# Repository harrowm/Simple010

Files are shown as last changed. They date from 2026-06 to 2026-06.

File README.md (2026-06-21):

# Simple010

A 68010 single-board computer based on the [rosco_m68k r2](https://github.com/rosco-m68k/rosco_m68k) design. Simple010 replaces the six discrete glue-logic ICs from that design with a single **ATF1508AS PLCC84 CPLD**, reducing board complexity while adding hardware SPI acceleration for SD card access.

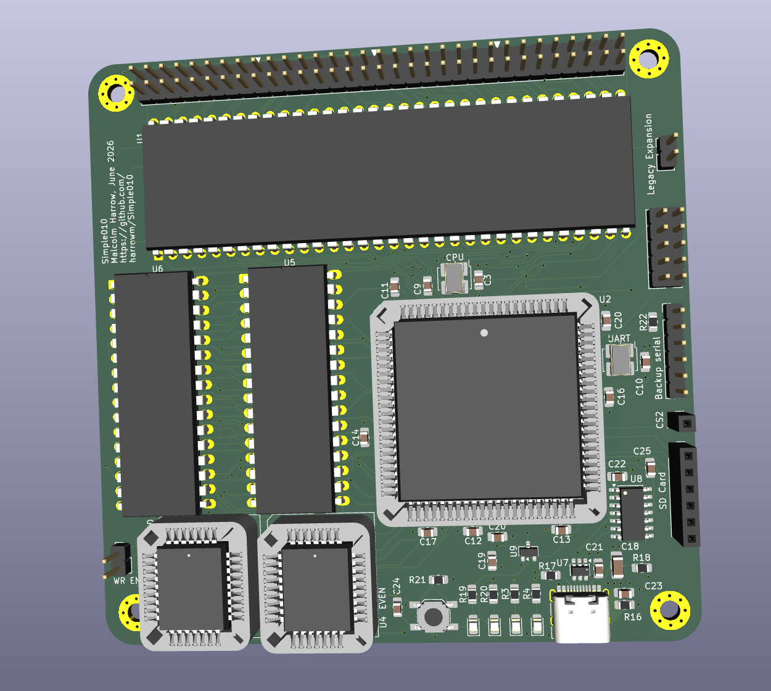
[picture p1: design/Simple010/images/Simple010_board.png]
Simple010 board


## Hardware overview

| Item | Detail |
|---|---|
| CPU | Motorola MC68010P at 10 MHz |
| RAM | 1 MB — two AS6C4008-55PCN SRAMs (even/odd byte lanes) |
| ROM | Two SST39SF040 4 Mb flash (even/odd byte lanes) |
| CPLD | ATF1508AS PLCC84 — replaces IC2/IC3/IC4/IC5/IC6/IC7 from rosco_m68k r2 |
| USB/serial | MCP2221A — USB-CDC serial to UART A. The original rosco_m68k board has two UARTs A and B. However, the code for two UARTs won't fit into the CPLD, so a cheaper one-channel USB-to-serial chip is used. |
| PCB | 4-layer, 100 × 100 mm, JLCPCB stackup (F.Cu / GND / PWR / B.Cu) |

### Memory map

| Range | Device |
|---|---|
| `$000000–$0FFFFF` | 1 MB SRAM |
| `$100000–$DFFFFF` | Expansion bus (DTACK from `LGEXP`) |
| `$E00000–$EFFFFF` | Flash ROM |
| `$F00000–$FFFFFF` | I/O — CPLD UART at `$F00000`, register select via A1–A4 |

### CPLD functional blocks

The CPLD (`code/cpld/cpld.v`) implements:

1. **Glue logic** — HALT/RESET open-drain drivers, CPU-space gating, boot flag
2. **Address decoder** — RAM, ROM, expansion, and I/O selects; DTACK; WR
3. **Watchdog** — 16-cycle timeout, asserts BERR open-drain
4. **UART A** — fixed 115200 8N1, XR68C681-compatible register map
5. **GPIO / OPR** — XR68C681 output port emulation; drives SPI CS, LEDs, MOSI, SCK
6. **SPI RX accelerator** — hardware-assisted SD card byte receive at ~1.843 MHz
7. **Interrupt priority encoder** — replaces 74LS148; encodes IRQ2/3/5/6 + UART RX into IPL2:1:0

Resource utilisation: **122/128 macro cells (95%)**.

## Repository layout

```
design/
  Simple010/            KiCad 10 schematic and PCB (1 MB SRAM)
    Simple010.kicad_sch   top-level (references four sub-sheets)
    CPU.kicad_sch         MC68010P, oscillator, expansion connector
    Memory.kicad_sch      SRAM, ROM, write-enable jumper
    CPLD.kicad_sch        ATF1508AS, JTAG header, LEDs, pull-ups
    USB.kicad_sch         MCP2221A, SD card, reset supervisor, power LEDs
    production/           Gerbers, BOM, position file
  Simple010-16/         KiCad 10 schematic and PCB (16 MB SRAM variant)
  datasheets/           component datasheets and parts index (INDEX.md)

code/cpld/       ATF1508AS Verilog RTL and testbench
  cpld.v                RTL source with //PIN: preassignment comments
  tb_cpld.v             testbench (120 assertions)
  build.sh              synthesis → fit → pin check → simulation
  cpld.jed              program this into the device
  cpld.fit / cpld.pin   fitter log and pin placement

rosco/           rosco_m68k firmware (git clone), modified for Simple010
```

## CPLD build

Requires [`atf15xx_yosys`](https://github.com/hoglet67/atf15xx_yosys.git) cloned into `~/atf15xx_yosys`, and `iverilog`/`vvp` on PATH.

```sh
cd code/cpld && ./build.sh
```

Expected output: `122/128 MCs used` and `120/120 tests passed`.

To run the testbench without re-synthesising:

```sh
cd code/cpld && iverilog -DSIMULATION -o tb_cpld tb_cpld.v cpld.v && vvp tb_cpld
```

The `-DSIMULATION` flag is required — without it 2 of 120 tests fail due to a cross-clock-domain handshake that behaves differently under deterministic simulation timing.

## Firmware

The firmware is the standard rosco_m68k r2 firmware cloned into `rosco/`, with minimal changes for Simple010 hardware.

The rosco directory is a clone of [rosco-m68k/rosco_m68k](https://github.com/rosco-m68k/rosco_m68k). Simple010 changes are on the `develop` branch, pushed to a fork at [harrowm/rosco_m68k](https://github.com/harrowm/rosco_m68k). The upstream is `origin`; the fork is `fork`:

```sh
cd rosco/rosco_m68k
git add <files>
git commit -m "description"
git push fork develop
```

### CPLD compatibility

The CPLD's UART emulates the XR68C681 (MC68681) at the register level. The existing rosco firmware DUART detection and initialisation code works without modification: the CPLD returns `0x0F` from the IVR register at reset, exactly as the real XR68C681 does.

### Simple010-specific changes

#### Startup detection — `stage1/main1.c`

At startup, after printing the standard CPU and memory information, the firmware reads the CPLD detection register and prints additional messages:

```
MC68010 CPU @ 10.0MHz with 1048576 bytes RAM
Simple010 CPLD v1 detected
  SPI RX accelerator present
```

**Detection mechanism:** reading byte address `0xF00005` (`DUART_R_MISR` in `machine.h`) returns a fixed capability byte from the CPLD:

| Bit | Mask | Meaning |
|-----|---|---|
| 7 | `0x80` | CPLD present (always 1) |
| 6 | `0x40` | SPI RX accelerator available |
| 1–0 | `0x03` | Bitstream version (currently 1) |

The combined value is `0xC1`. On the original XR68C681, this register is MISR (masked interrupt status), which reads ~`0x00` at boot — so the detection is safe on original rosco hardware and the CPLD messages simply do not appear.

> **Address note:** the CPLD's `uart_sel` is gated on `~LDS` (lower data strobe), so the access must target the **odd** byte address `0xF00005`. Reading even address `0xF00004` (upper data strobe / UDS) will not reach the CPLD.

#### SPI RX accelerator — `stage1/blockdev/bbspi.c`

The CPLD includes a hardware SPI byte-receive engine clocked at ~1.843 MHz (UART_CLK ÷ 2), reducing per-byte bus traffic from ~24 cycles to 2 cycles compared to bit-banging.

`BBSPI_initialize()` detects the accelerator by reading `0xF00005` and caches the result in a `static bool cpld_spi_accel`. `BBSPI_recv_byte()` and `BBSPI_recv_buffer()` then dispatch on this flag:

**Accelerated receive sequence (per byte):**

| Step | Action | Address |
|---|---|---|
| 1 | Write any value to SPIRX register — triggers one 8-bit receive | `0xF00009` (write) |
| 2 | Poll SRA bit 2 (`spi_busy`) until clear | `0xF00003` (read) |
| 3 | Read received byte from SPIRX register | `0xF00009` (read) |

Send operations (`BBSPI_send_byte`, `BBSPI_send_buffer`) are unchanged — they continue to bit-bang through the CPLD GPIO, which is correct since the SD card protocol is heavily read-biased and transmit calls are infrequent. On original rosco hardware, `cpld_spi_accel` is `false` and both receive functions fall back to the existing bit-bang asm routines in `dua_spi_asm.asm`.

## Parts and ordering

See [`design/datasheets/INDEX.md`](design/datasheets/INDEX.md) for a full BOM with LCSC and Mouser part numbers.

Key sourcing notes:
- **ATF1508AS-15JU84** — not on LCSC; order from Microchip direct, Mouser (556-AF1508AS15JU84), or DigiKey
- **MC68010P** — EOL; source from eBay or second-hand market
- **SST39SF040 PLCC-32** — not stocked on LCSC; use Mouser (579-SST39SF040-70-4I-NHE)

## Acknowledgements

Simple010 is based on the [rosco_m68k](https://github.com/rosco-m68k/rosco_m68k) project by Ross Bamford and contributors. The schematic topology, memory map, and firmware are derived from the rosco_m68k r2 mainboard design.

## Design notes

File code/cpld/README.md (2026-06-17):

# rosco_m68k r2 CPLD — ATF1508AS PLCC84

Replaces IC2 (address decoder), IC3 (DUART select), IC5 (glue logic),
IC6 (watchdog), IC4 (XR68C681 UART A, fixed 115200 8N1), and IC7 (74LS148
interrupt priority encoder) with a single ATF1508AS CPLD.

## Build

Requires [atf15xx_yosys](https://github.com/hoglet67/atf15xx_yosys.git) cloned
into `~/atf15xx_yosys`, and `iverilog`/`vvp` on PATH.

```
./build.sh
```

Runs synthesis, fits the design, verifies all 56 pin preassignments are
respected, then runs the testbench. Expected output:

```
Synthesising... done.
Fitting... done.  Fitter completed — 122/128 MCs used.
Checking pin assignments... all 56 assignments respected.
Running testbench... 120/120 tests passed.
```

On failure the script exits non-zero and prints the specific error (mismatched
pins or failing test assertions).

## Testing only

To run the testbench without re-synthesising:

```
iverilog -DSIMULATION -o tb_cpld tb_cpld.v cpld.v && vvp tb_cpld
```

The `-DSIMULATION` flag is required — without it only 118/120 tests pass.
The two affected tests exercise the RBA-read/cpu_rd_rba handshake: in synthesis
this is a 1-cycle SYS_CLK pulse (~124 ns) that can be missed by UART_CLK
(~270 ns period); the simulation path holds the signal until UART_CLK acks.

## Files

| File | Description |
|---|---|
| `cpld.v` | RTL source and `//PIN:` preassignment comments |
| `tb_cpld.v` | Testbench (120 assertions) |
| `build.sh` | Synthesis + fit + pin check + simulation |
| `cpld.jed` | Fitter output — program this into the device |
| `cpld.fit` | Fitter log (resource usage, pin placement) |
| `cpld.pin` | Pin placement file (generated by fitter) |

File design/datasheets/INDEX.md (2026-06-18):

# Simple010 Component Datasheets

Datasheets for all active components on the Simple010 board.
LCSC numbers are for JLCPCB ordering. Mouser numbers are for Mouser ordering.

## ICs

| Ref | Value | LCSC | Mouser | Datasheet |
|-----|---|---|---|---|
| U1 | MC68010P — 68010 CPU | — | — | [MC68010.pdf](MC68010.pdf) |
| U2 | ATF1508AS — CPLD PLCC84 | — | — | [ATF1508AS.pdf](ATF1508AS.pdf) |
| U3, U4 | SST39SF040 — 4Mb Flash ROM PLCC-32 | — (PLCC-32 not stocked on LCSC) | 579-SST39SF040-70-4I-NHE | [SST39SF040.pdf](SST39SF040.pdf) |
| U5, U6 | AS6C4008-55PCN — 512K×8 SRAM | C1350141 (OOS) | 913-AS6C4008-55PCN | [AS6C4008.pdf](AS6C4008.pdf) |
| U8 | MCP2221A — USB↔UART/I²C bridge | C640876 | 579-MCP2221A-I/SL | [MCP2221A.pdf](MCP2221A.pdf) |
| U7 | USBLC6-2SC6 — USB ESD protection | C7519 | 511-USBLC6-2SC6 | [USBLC6-2SC6.pdf](USBLC6-2SC6.pdf) |
| U9 | LM809M3-4.63/NOPB — 4.63V reset supervisor SOT-23 | C2066444 | 595-LM809M3-4.63NOPB | [LM809.pdf](LM809.pdf) |

## Oscillators

| Ref | Value | LCSC | Mouser | Datasheet |
|-----|---|---|---|---|
| Y1 | SG-5032CAN 10MHz (ECS-3961-100) — CPU clock | C41361451 | ECS-3961-100-AU-TR | [ECS-3961_SG-5032CAN.pdf](ECS-3961_SG-5032CAN.pdf) |
| Y2 | SG-5032CAN 3.6864MHz (ECS-3961-036) — UART baud clock | C5382652 | ECS-3961-036-AU-TR | [ECS-3961_SG-5032CAN.pdf](ECS-3961_SG-5032CAN.pdf) |

## LEDs

| Ref | Value | LCSC | Mouser | Datasheet |
|-----|---|---|---|---|
| LED1, LED3 | LTST-C170KGKT — 0805 Green LED | C961277 | LTST-C170KGKT | [LTST-C170KGKT.pdf](LTST-C170KGKT.pdf) |
| LED2, LED4 | LTST-C170KRKT — 0805 Red LED | C961276 | LTST-C170KRKT | [LTST-C170KRKT.pdf](LTST-C170KRKT.pdf) |

## Switches & Connectors

| Ref | Value | LCSC | Mouser | Datasheet |
|-----|---|---|---|---|
| SW1 | XKB TS-1187A-B-A-B — 5.1×5.1mm SMD tact switch | C318884 | — | [TS-1187A_SW1.pdf](TS-1187A_SW1.pdf) |
| J3 | Korean Hroparts TYPE-C-31-M-12 — USB-C receptacle 16P | C165948 | — | [TYPE-C-31-M-12_USB-C.pdf](TYPE-C-31-M-12_USB-C.pdf) |

## Passives (all 0805 unless noted)

All passives are JLCPCB **Basic** parts — no extended part setup fees.
UNI-ROYAL resistors are sold as "Royalohm" on Mouser; search by manufacturer PN.

| Value | Refs | LCSC | Manufacturer PN | Mouser |
|---|---|---|---|---|
| 100nF MLCC X7R | C1–C3, C5–C17, C20–C22, C24 | C49678 | Yageo CC0805KRX7R9BB104 | 603-CC0805KRX7R9BB104 |
| 100pF MLCC C0G/NP0 | C23 | C1790 | Samsung CL21C101JBANNNC | 187-CL21C101JBANNNC |
| 470nF MLCC X7R | C25 | C13967 | Samsung CL21B474KBFNNNE | 187-CL21B474KBFNNNE |
| 10µF MLCC X5R 25V | C4, C19 | C15850 | Samsung CL21A106KAYNNNE | 187-CL21A106KAYNNNE |
| 47µF MLCC X5R 10V **1206** | C18 | C96123 | Samsung CL31A476MPHNNNE | 187-CL31A476MPHNNNE |
| 1kΩ 1% | R3, R4, R19–R21 | C17513 | UNI-ROYAL 0805W8F1001T5E | 0805W8F1001T5E |
| 1.2kΩ 1% | R5 | C17379 | UNI-ROYAL 0805W8F1201T5E | 0805W8F1201T5E |
| 4.7kΩ 1% | R6–R15, R22 | C17673 | UNI-ROYAL 0805W8F4701T5E | 0805W8F4701T5E |
| 5.1kΩ 1% | R17, R18 | C27834 | UNI-ROYAL 0805W8F5101T5E | 0805W8F5101T5E |
| 10kΩ 1% | R1, R2 | C17414 | UNI-ROYAL 0805W8F1002T5E | 0805W8F1002T5E |
| 1MΩ 1% | R16 | C17514 | UNI-ROYAL 0805W8F1004T5E | 0805W8F1004T5E |

---

## Notes

**ATF1508AS LCSC:** The ATF1508AS-15JU84 (PLCC84, 5V, 15ns) is not stocked on LCSC/JLCPCB. Order directly from Microchip or via a distributor such as Mouser (556-AF1508AS15JU84) or DigiKey.

**MC68010P LCSC:** Not available on LCSC. Source from eBay/second-hand market, or Mouser (was stocked as NXP MC68010P10, now EOL).

**Mouser numbers** correspond to the same manufacturer as the LCSC part throughout. UNI-ROYAL resistors are listed on Mouser under the Royalohm brand; search by manufacturer PN (e.g. 0805W8F4701T5E).

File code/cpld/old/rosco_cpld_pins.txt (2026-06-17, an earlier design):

CHIP "rosco_cpld" ASSIGNED TO AN PLCC84
HWRST                : 1
SYS_CLK              : 2
VCC                  : 3
D_2                  : 4
D_0                  : 5
A20                  : 6
GND                  : 7
D_4                  : 8
nEXPSEL              : 9
nIOSEL               : 10
SPI_nCS              : 11
WR                   : 12
VCC                  : 13
TDI                  : 14
D_6                  : 15
SPI_MOSI             : 16
RW                   : 17
AS                   : 18
GND                  : 19
A23                  : 20
A22                  : 21
A21                  : 22
TMS                  : 23
D_3                  : 24
D_1                  : 25
VCC                  : 26
D_7                  : 27
D_5                  : 28
nODDROMSEL           : 29
nODDRAMSEL           : 30
nEVENRAMSEL          : 31
GND                  : 32
RXA                  : 33
A19                  : 34
UDS                  : 35
SPI_MISO             : 36
LDS                  : 37
VCC                  : 38
A4                   : 39
A1                   : 40
A3                   : 41
GND                  : 42
VCC                  : 43
nIRQ6                : 44
nIRQ3                : 45
nIRQ5                : 46
GND                  : 47
LGEXP                : 48
A18                  : 49
nIRQ2                : 50
NC                   : 51
TXA                  : 52
VCC                  : 53
FC0                  : 54
FC1                  : 55
FC2                  : 56
A2                   : 57
IPL2                 : 58
GND                  : 59
NC                   : 60
IPL0                 : 61
TCK                  : 62
NC                   : 63
NC                   : 64
NC                   : 65
VCC                  : 66
NC                   : 67
NC                   : 68
nEVENROMSEL          : 69
IPL1                 : 70
TDO                  : 71
GND                  : 72
LED_RED              : 73
SPI_nCS1             : 74
LED_GREEN            : 75
BERR                 : 76
DTACK                : 77
VCC                  : 78
RESET                : 79
HALT                 : 80
SPI_SCK              : 81
GND                  : 82
UART_CLK             : 83
NC                   : 84

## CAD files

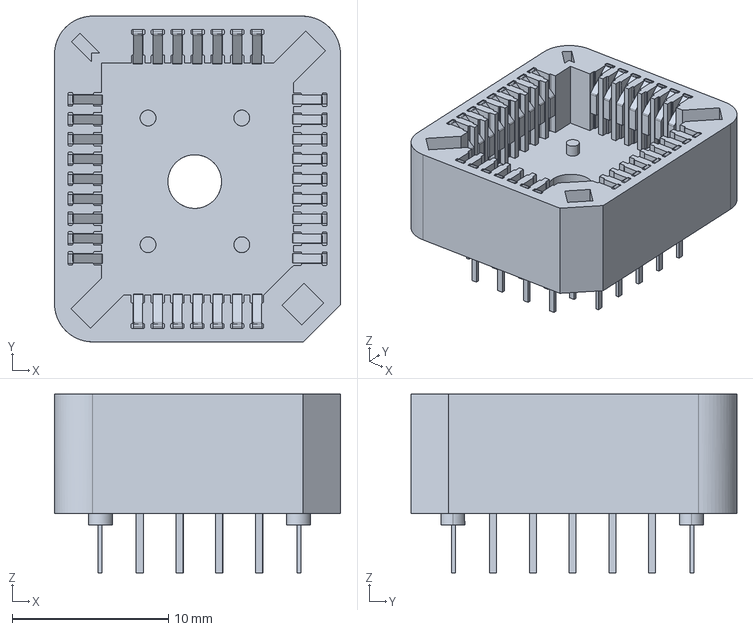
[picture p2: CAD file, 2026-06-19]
design/Simple010/3DModels/8432-11b1-01.stp
18.3 x 20.8 x 11.4 mm

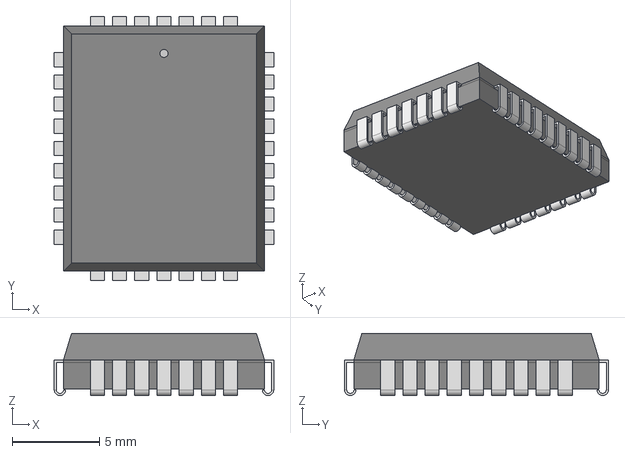
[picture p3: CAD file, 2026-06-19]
design/Simple010/3DModels/PLCC32_NH_SST_MCH.step
12.6 x 15.1 x 3.56 mm

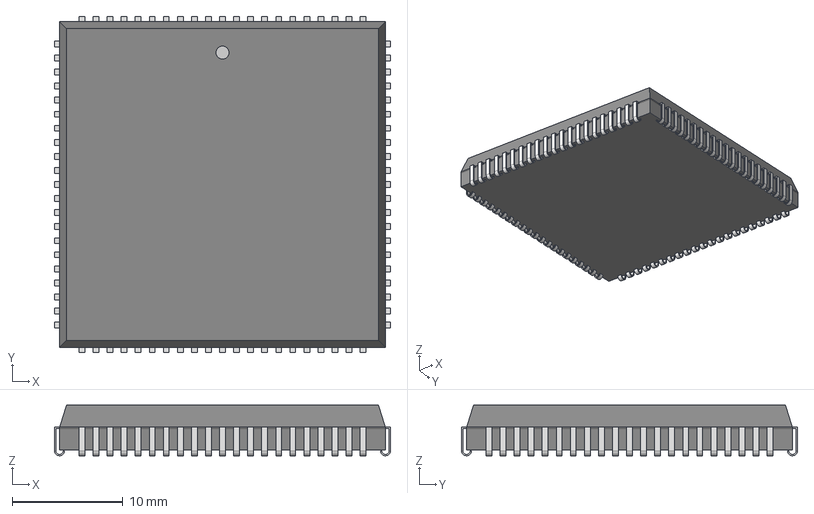
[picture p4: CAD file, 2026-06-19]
design/Simple010/3DModels/PLCC84_MCH.step
30.4 x 30.4 x 4.58 mm

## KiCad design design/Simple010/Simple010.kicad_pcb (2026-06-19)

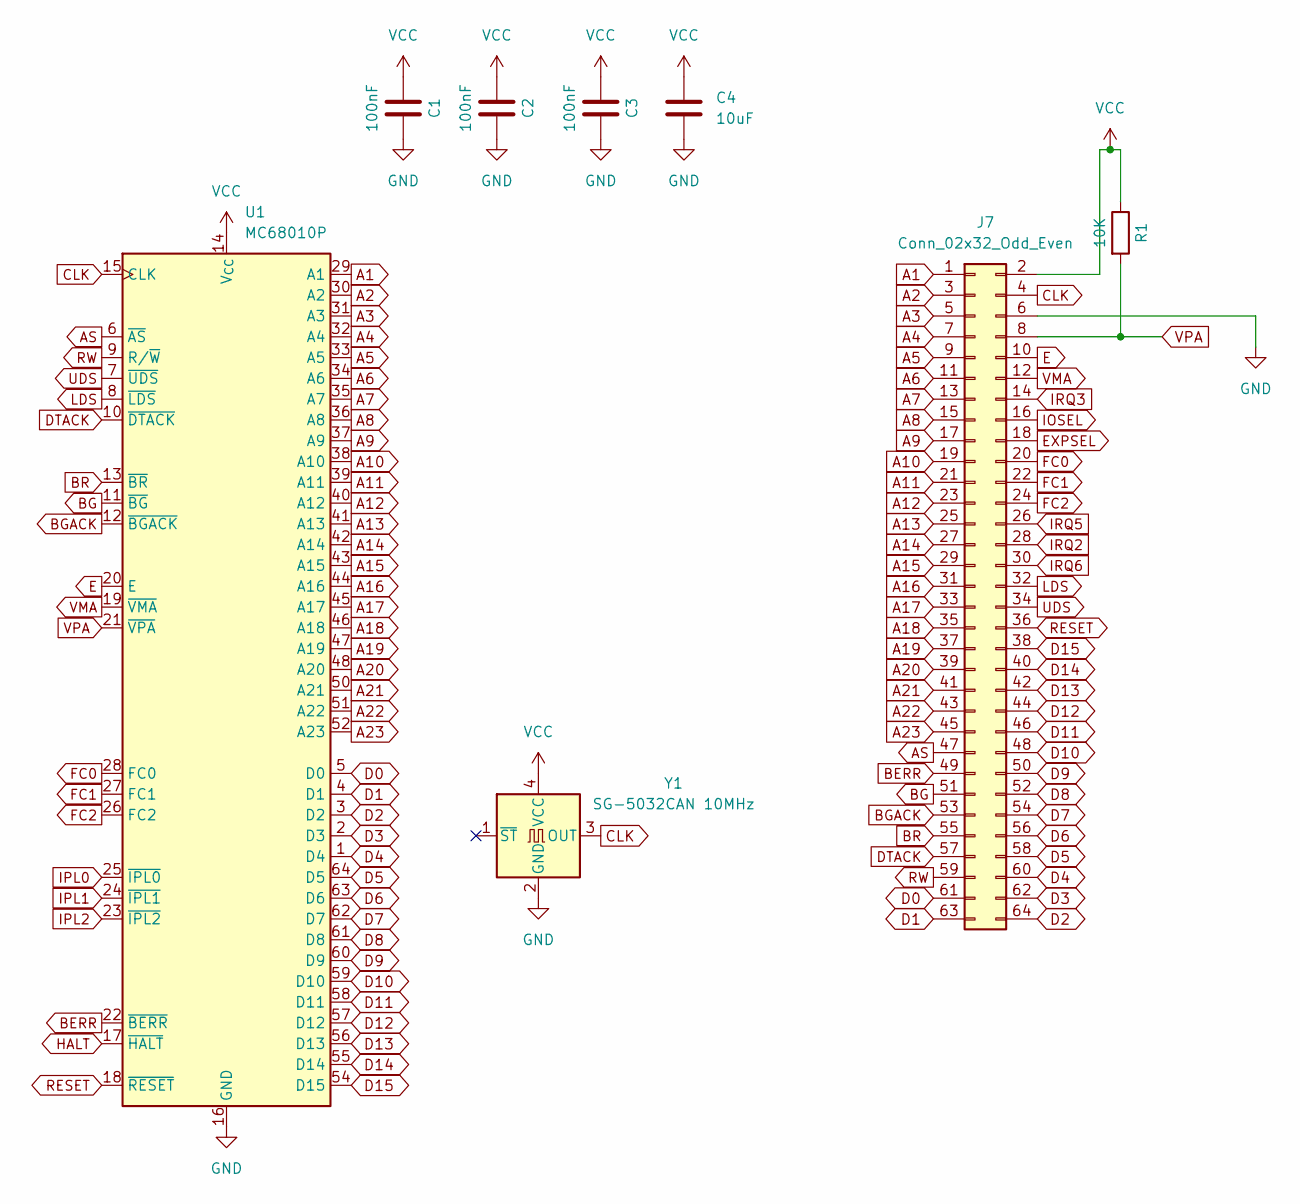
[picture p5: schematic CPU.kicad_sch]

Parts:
C1, C2, C3: 100nF; C_0805_2012Metric_Pad1.18x1.45mm_HandSolder; LCSC C49678
C4: 10uF; C_0805_2012Metric_Pad1.18x1.45mm_HandSolder; Mouser 187-CL21A106KAYNNNE
J7: Conn_02x32_Odd_Even; PinHeader_2x32_P2.54mm_Vertical
R1: 10K; R_0805_2012Metric_Pad1.20x1.40mm_HandSolder; Mouser 0805W8F1002T5E
U1: MC68010P; DIP-64_W22.86mm
Y1: SG-5032CAN 10MHz; Oscillator_SMD_SeikoEpson_SG8002LB-4Pin_5.0x3.2mm_HandSolde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; Mouser ECS-3961-100-AU-TR

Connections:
A1: J7.1, U1.29 (A1); also elsewhere on the board
A2: J7.3, U1.30 (A2); also elsewhere on the board
A3: J7.5, U1.31 (A3); also elsewhere on the board
A4: J7.7, U1.32 (A4); also elsewhere on the board
A5: J7.9, U1.33 (A5); also elsewhere on the board
A6: J7.11, U1.34 (A6); also elsewhere on the board
A7: J7.13, U1.35 (A7); also elsewhere on the board
A8: J7.15, U1.36 (A8); also elsewhere on the board
A9: J7.17, U1.37 (A9); also elsewhere on the board
A10: J7.19, U1.38 (A10); also elsewhere on the board
A11: J7.21, U1.39 (A11); also elsewhere on the board
A12: J7.23, U1.40 (A12); also elsewhere on the board
A13: J7.25, U1.41 (A13); also elsewhere on the board
A14: J7.27, U1.42 (A14); also elsewhere on the board
A15: J7.29, U1.43 (A15); also elsewhere on the board
A16: J7.31, U1.44 (A16); also elsewhere on the board
A17: J7.33, U1.45 (A17); also elsewhere on the board
A18: J7.35, U1.46 (A18); also elsewhere on the board
A19: J7.37, U1.47 (A19); also elsewhere on the board
A20: J7.39, U1.48 (A20); also elsewhere on the board
A21: J7.41, U1.50 (A21); also elsewhere on the board
A22: J7.43, U1.51 (A22); also elsewhere on the board
A23: J7.45, U1.52 (A23); also elsewhere on the board
AS: J7.47, U1.6 (~AS); also elsewhere on the board
BERR: J7.49, U1.22 (~BERR); also elsewhere on the board
BG: J7.51, U1.11 (~BG)
BGACK: J7.53, U1.12 (~BGACK); also elsewhere on the board
BR: J7.55, U1.13 (~BR); also elsewhere on the board
CLK: J7.4, U1.15 (CLK), Y1.3 (OUT); also elsewhere on the board
D0: J7.61, U1.5 (D0); also elsewhere on the board
D1: J7.63, U1.4 (D1); also elsewhere on the board
D2: J7.64, U1.3 (D2); also elsewhere on the board
D3: J7.62, U1.2 (D3); also elsewhere on the board
D4: J7.60, U1.1 (D4); also elsewhere on the board
D5: J7.58, U1.64 (D5); also elsewhere on the board
D6: J7.56, U1.63 (D6); also elsewhere on the board
D7: J7.54, U1.62 (D7); also elsewhere on the board
D8: J7.52, U1.61 (D8); also elsewhere on the board
D9: J7.50, U1.60 (D9); also elsewhere on the board
D10: J7.48, U1.59 (D10); also elsewhere on the board
D11: J7.46, U1.58 (D11); also elsewhere on the board
D12: J7.44, U1.57 (D12); also elsewhere on the board
D13: J7.42, U1.56 (D13); also elsewhere on the board
D14: J7.40, U1.55 (D14); also elsewhere on the board
D15: J7.38, U1.54 (D15); also elsewhere on the board
DTACK: J7.57, U1.10 (~DTACK); also elsewhere on the board
E: J7.10, U1.20 (E)
EXPSEL: J7.18; also elsewhere on the board
FC0: J7.20, U1.28 (FC0); also elsewhere on the board
FC1: J7.22, U1.27 (FC1); also elsewhere on the board
FC2: J7.24, U1.26 (FC2); also elsewhere on the board
GND: C1.2, C2.2, C3.2, C4.2, J7.6, U1.16 (GND), U1.53 (GND), Y1.2 (GND); also elsewhere on the board
HALT: U1.17 (~HALT); also elsewhere on the board
IOSEL: J7.16; also elsewhere on the board
IPL0: U1.25 (~IPL0); also elsewhere on the board
IPL1: U1.24 (~IPL1); also elsewhere on the board
IPL2: U1.23 (~IPL2); also elsewhere on the board
IRQ2: J7.28; also elsewhere on the board
IRQ3: J7.14; also elsewhere on the board
IRQ5: J7.26; also elsewhere on the board
IRQ6: J7.30; also elsewhere on the board
LDS: J7.32, U1.8 (~LDS); also elsewhere on the board
RESET: J7.36, U1.18 (~RESET); also elsewhere on the board
RW: J7.59, U1.9 (R/~W); also elsewhere on the board
UDS: J7.34, U1.7 (~UDS); also elsewhere on the board
VCC: C1.1, C2.1, C3.1, C4.1, J7.2, R1.1, U1.14 (V_{CC}), U1.49 (V_{CC}), Y1.4 (VCC); also elsewhere on the board
VMA: J7.12, U1.19 (~VMA)
VPA: J7.8, R1.2, U1.21 (~VPA)

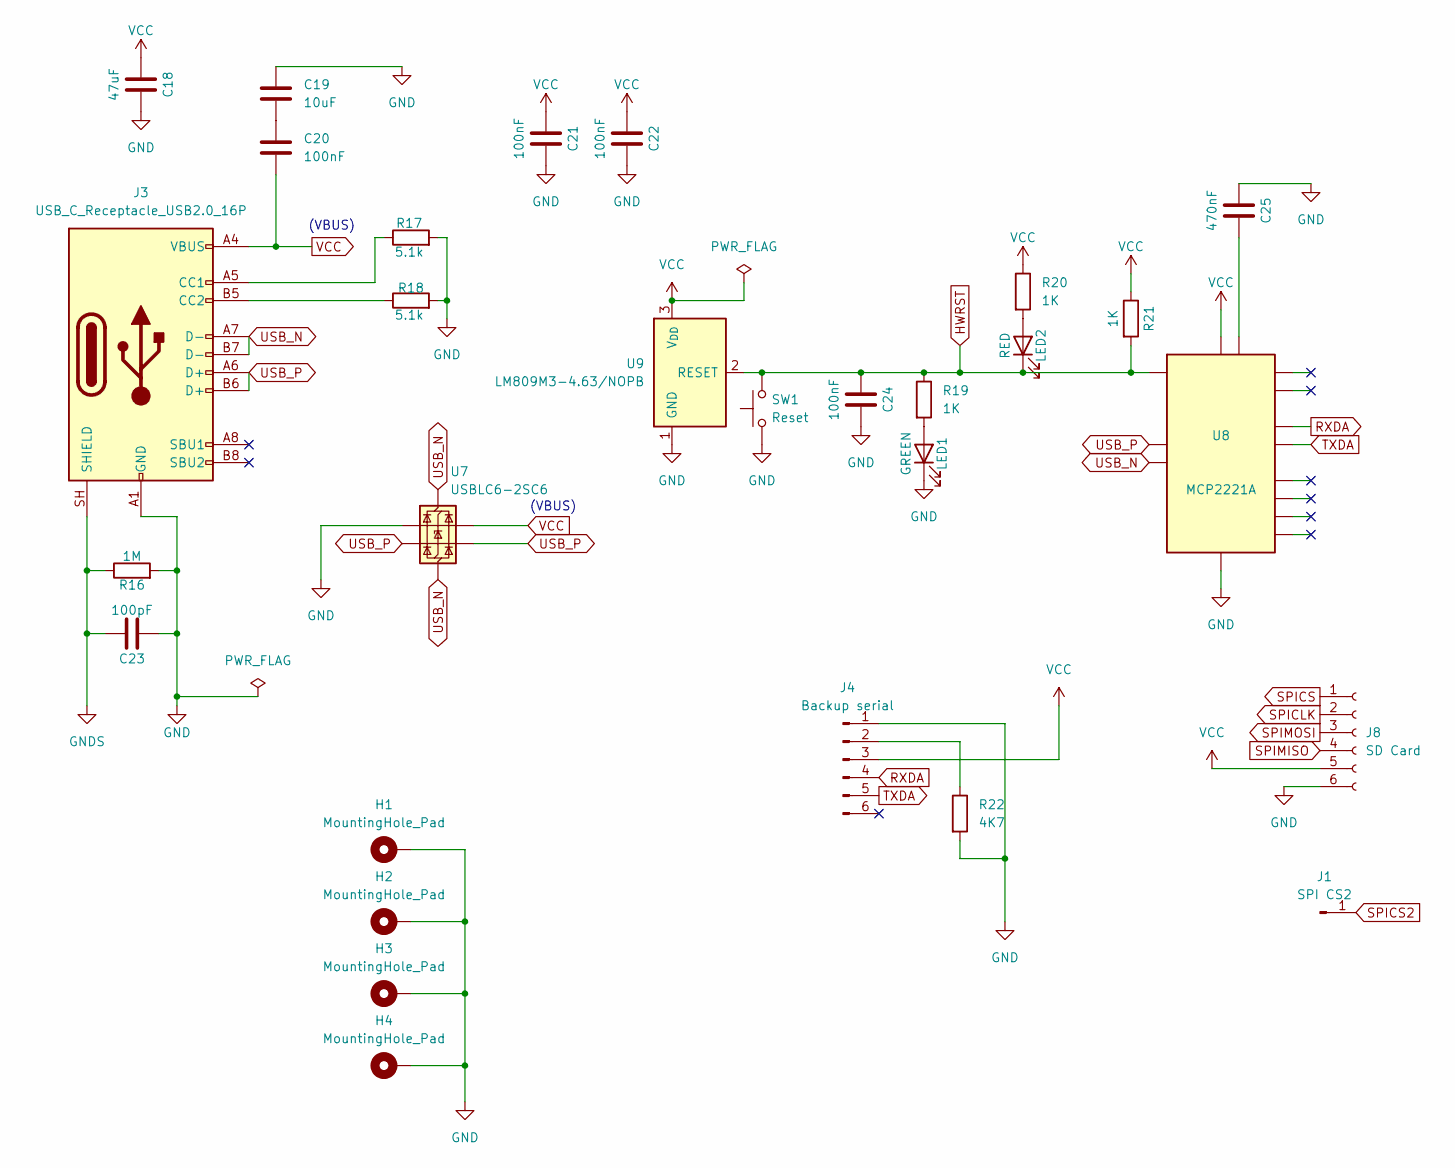
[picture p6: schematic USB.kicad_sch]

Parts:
C18: 47uF; C_1206_3216Metric_Pad1.33x1.80mm_HandSolder; LCSC C96123
C19: 10uF; C_0805_2012Metric_Pad1.18x1.45mm_HandSolder; Mouser 187-CL21A106KAYNNNE
C20, C21, C22, C24: 100nF; C_0805_2012Metric_Pad1.18x1.45mm_HandSolder; LCSC C49678
C23: 100pF; C_0805_2012Metric_Pad1.18x1.45mm_HandSolder; Mouser 187-CL21C101JBANNNC
C25: 470nF; C_0805_2012Metric_Pad1.18x1.45mm_HandSolder; Mouser 187-CL21B474KBFNNNE
H1, H2, H3, H4: MountingHole_Pad; MountingHole_3.2mm_M3_Pad_Via
J1: SPI CS2; PinSocket_1x01_P2.54mm_Vertical
J3: USB_C_Receptacle_USB2.0_16P; USB_C_Receptacle_HRO_TYPE-C-31-M-12; Mouser 649-10171746-00021LF
J4: Backup serial; PinHeader_1x06_P2.54mm_Vertical
J8: SD Card; PinSocket_1x06_P2.54mm_Vertical
LED1: GREEN; LED_0805_2012Metric_Pad1.15x1.40mm_HandSolder
LED2: RED; LED_0805_2012Metric_Pad1.15x1.40mm_HandSolder
R16: 1M; R_0805_2012Metric_Pad1.20x1.40mm_HandSolder; Mouser 0805W8F1004T5E
R17, R18: 5.1k; R_0805_2012Metric_Pad1.20x1.40mm_HandSolder; Mouser 0805W8F5101T5E
R19, R20: 1K; R_0805_2012Metric_Pad1.20x1.40mm_HandSolder; LCSC C17513
R21: 1K; R_0805_2012Metric_Pad1.20x1.40mm_HandSolder; Mouser 0805W8F1001T5E
R22: 4K7; R_0805_2012Metric_Pad1.20x1.40mm_HandSolder; LCSC C17673
SW1: Reset; SW_SPST_SKQG_WithoutStem; LCSC C318884
U7: USBLC6-2SC6; SOT-23-6; Mouser 511-USBLC6-2SC6
U8: MCP2221A; SOIC-14_3.9x8.7mm_P1.27mm; Mouser 579-MCP2221A-I/SL
U9: LM809M3-4.63/NOPB; SOT-23; LCSC C2066444

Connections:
GND: C18.2, C19.1, C21.2, C22.2, C23.2, C24.2, C25.1, H1.1 (1_1), H2.1 (1_1), H3.1 (1_1), H4.1 (1_1), J3.A1 (GND), J3.A12 (GND), J3.B1 (GND), J3.B12 (GND), J4.1, J8.6, LED1.1 (K), R16.2, R17.2, R18.2, R22.2, SW1.1, U7.1 (I/O1), U8.14 (VSS), U9.1 (GND); also elsewhere on the board
GNDS: C23.1, J3.SH (SHIELD), R16.1
HWRST: C24.1, LED2.1 (K), R19.1, R21.2, SW1.2, U8.4 (~RST), U9.2 (RESET); also elsewhere on the board
unnamed: C19.2, C20.1
unnamed: J3.A5 (CC1), R17.1
unnamed: J3.B5 (CC2), R18.1
unnamed: J4.2, R22.1
unnamed: LED1.2 (A), R19.2
unnamed: LED2.2 (A), R20.2
unnamed: C25.2, U8.11 (VUSB)
RXDA: J4.4, U8.5 (URx); also elsewhere on the board
SPICLK: J8.2; also elsewhere on the board
SPICS: J8.1; also elsewhere on the board
SPICS2: J1.1 (Pin_1_1); also elsewhere on the board
SPIMISO: J8.4; also elsewhere on the board
SPIMOSI: J8.3; also elsewhere on the board
TXDA: J4.5, U8.6 (UTx); also elsewhere on the board
USB_N: J3.A7 (D-), J3.B7 (D-), U7.2 (GND), U7.5 (VBUS), U8.12 (D-)
USB_P: J3.A6 (D+), J3.B6 (D+), U7.3 (I/O2), U7.4 (I/O2), U8.13 (D+)
VCC: C18.1, C20.2, C21.1, C22.1, J3.A4 (VBUS), J3.A9 (VBUS), J3.B4 (VBUS), J3.B9 (VBUS), J4.3, J8.5, R20.1, R21.1, U7.6 (I/O1), U8.1 (VDD), U9.3 (V_{DD}); also elsewhere on the board

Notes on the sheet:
(VBUS)

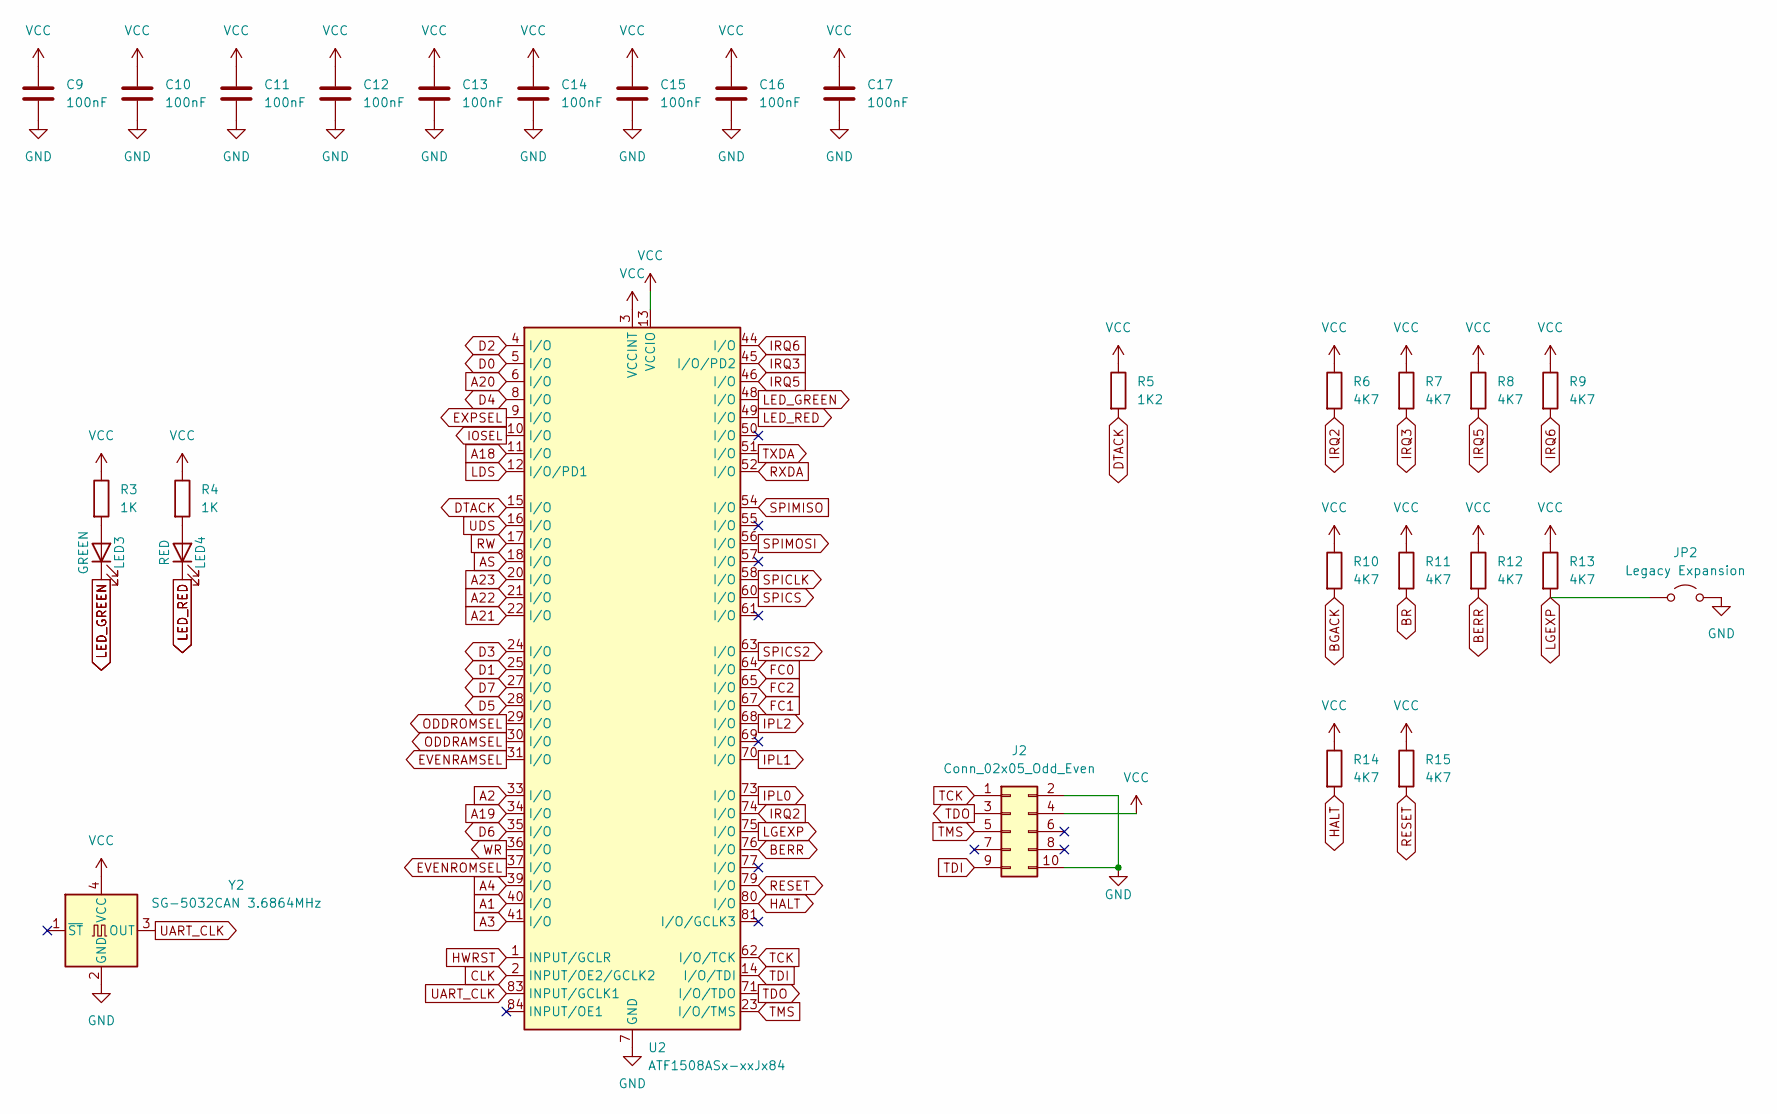
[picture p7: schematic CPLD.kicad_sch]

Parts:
C9, C10, C11, C12, C13, C14, C15, C16, C17: 100nF; C_0805_2012Metric_Pad1.18x1.45mm_HandSolder; Mouser 603-CC0805KRX7R9BB104
J2: Conn_02x05_Odd_Even; PinHeader_2x05_P2.54mm_Vertical
JP2: Legacy Expansion; PinHeader_1x02_P2.54mm_Vertical
LED3: GREEN; LED_0805_2012Metric_Pad1.15x1.40mm_HandSolder; LCSC C961277
LED4: RED; LED_0805_2012Metric_Pad1.15x1.40mm_HandSolder; LCSC C961276
R3, R4: 1K; R_0805_2012Metric_Pad1.20x1.40mm_HandSolder; LCSC C17513
R5: 1K2; R_0805_2012Metric_Pad1.20x1.40mm_HandSolder; LCSC C17379
R6, R7, R8, R9, R10, R11, R12, R13, R14, R15: 4K7; R_0805_2012Metric_Pad1.20x1.40mm_HandSolder; LCSC C17673
U2: ATF1508ASx-xxJx84; PLCC-84_THT-Socket
Y2: SG-5032CAN 3.6864MHz; Oscillator_SMD_SeikoEpson_SG8002LB-4Pin_5.0x3.2mm_HandSolde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; Mouser ECS-3961-036-AU-TR

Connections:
A1: U2.40 (I/O); also elsewhere on the board
A2: U2.33 (I/O); also elsewhere on the board
A3: U2.41 (I/O); also elsewhere on the board
A4: U2.39 (I/O); also elsewhere on the board
A18: U2.11 (I/O); also elsewhere on the board
A19: U2.34 (I/O); also elsewhere on the board
A20: U2.6 (I/O); also elsewhere on the board
A21: U2.22 (I/O); also elsewhere on the board
A22: U2.21 (I/O); also elsewhere on the board
A23: U2.20 (I/O); also elsewhere on the board
AS: U2.18 (I/O); also elsewhere on the board
BERR: R12.2, U2.76 (I/O); also elsewhere on the board
BGACK: R10.2; also elsewhere on the board
BR: R11.2; also elsewhere on the board
CLK: U2.2 (INPUT/OE2/GCLK2); also elsewhere on the board
D0: U2.5 (I/O); also elsewhere on the board
D1: U2.25 (I/O); also elsewhere on the board
D2: U2.4 (I/O); also elsewhere on the board
D3: U2.24 (I/O); also elsewhere on the board
D4: U2.8 (I/O); also elsewhere on the board
D5: U2.28 (I/O); also elsewhere on the board
D6: U2.35 (I/O); also elsewhere on the board
D7: U2.27 (I/O); also elsewhere on the board
DTACK: R5.2, U2.15 (I/O); also elsewhere on the board
EVENRAMSEL: U2.31 (I/O); also elsewhere on the board
EVENROMSEL: U2.37 (I/O); also elsewhere on the board
EXPSEL: U2.9 (I/O); also elsewhere on the board
FC0: U2.64 (I/O); also elsewhere on the board
FC1: U2.67 (I/O); also elsewhere on the board
FC2: U2.65 (I/O); also elsewhere on the board
GND: C9.2, C10.2, C11.2, C12.2, C13.2, C14.2, C15.2, C16.2, C17.2, J2.2, J2.10, JP2.2 (B), U2.7 (GND), U2.19 (GND), U2.32 (GND), U2.42 (GND), U2.47 (GND), U2.59 (GND), U2.72 (GND), U2.82 (GND), Y2.2 (GND); also elsewhere on the board
HALT: R14.2, U2.80 (I/O); also elsewhere on the board
HWRST: U2.1 (INPUT/GCLR); also elsewhere on the board
IOSEL: U2.10 (I/O); also elsewhere on the board
IPL0: U2.73 (I/O); also elsewhere on the board
IPL1: U2.70 (I/O); also elsewhere on the board
IPL2: U2.68 (I/O); also elsewhere on the board
IRQ2: R6.2, U2.74 (I/O); also elsewhere on the board
IRQ3: R7.2, U2.45 (I/O/PD2); also elsewhere on the board
IRQ5: R8.2, U2.46 (I/O); also elsewhere on the board
IRQ6: R9.2, U2.44 (I/O); also elsewhere on the board
LDS: U2.12 (I/O/PD1); also elsewhere on the board
LED_GREEN: LED3.1 (K), U2.48 (I/O)
LED_RED: LED4.1 (K), U2.49 (I/O)
LGEXP: JP2.1 (A), R13.2, U2.75 (I/O)
unnamed: LED3.2 (A), R3.2
unnamed: LED4.2 (A), R4.2
ODDRAMSEL: U2.30 (I/O); also elsewhere on the board
ODDROMSEL: U2.29 (I/O); also elsewhere on the board
RESET: R15.2, U2.79 (I/O); also elsewhere on the board
RW: U2.17 (I/O); also elsewhere on the board
RXDA: U2.52 (I/O); also elsewhere on the board
SPICLK: U2.58 (I/O); also elsewhere on the board
SPICS: U2.60 (I/O); also elsewhere on the board
SPICS2: U2.63 (I/O); also elsewhere on the board
SPIMISO: U2.54 (I/O); also elsewhere on the board
SPIMOSI: U2.56 (I/O); also elsewhere on the board
TCK: J2.1, U2.62 (I/O/TCK)
TDI: J2.9, U2.14 (I/O/TDI)
TDO: J2.3, U2.71 (I/O/TDO)
TMS: J2.5, U2.23 (I/O/TMS)
TXDA: U2.51 (I/O); also elsewhere on the board
UART_CLK: U2.83 (INPUT/GCLK1), Y2.3 (OUT)
UDS: U2.16 (I/O); also elsewhere on the board
VCC: C9.1, C10.1, C11.1, C12.1, C13.1, C14.1, C15.1, C16.1, C17.1, J2.4, R3.1, R4.1, R5.1, R6.1, R7.1, R8.1, R9.1, R10.1, R11.1, R12.1, R13.1, R14.1, R15.1, U2.3 (VCCINT), U2.13 (VCCIO), U2.26 (VCCIO), U2.38 (VCCIO), U2.43 (VCCINT), U2.53 (VCCIO), U2.66 (VCCIO), U2.78 (VCCIO), Y2.4 (VCC); also elsewhere on the board
WR: U2.36 (I/O); also elsewhere on the board

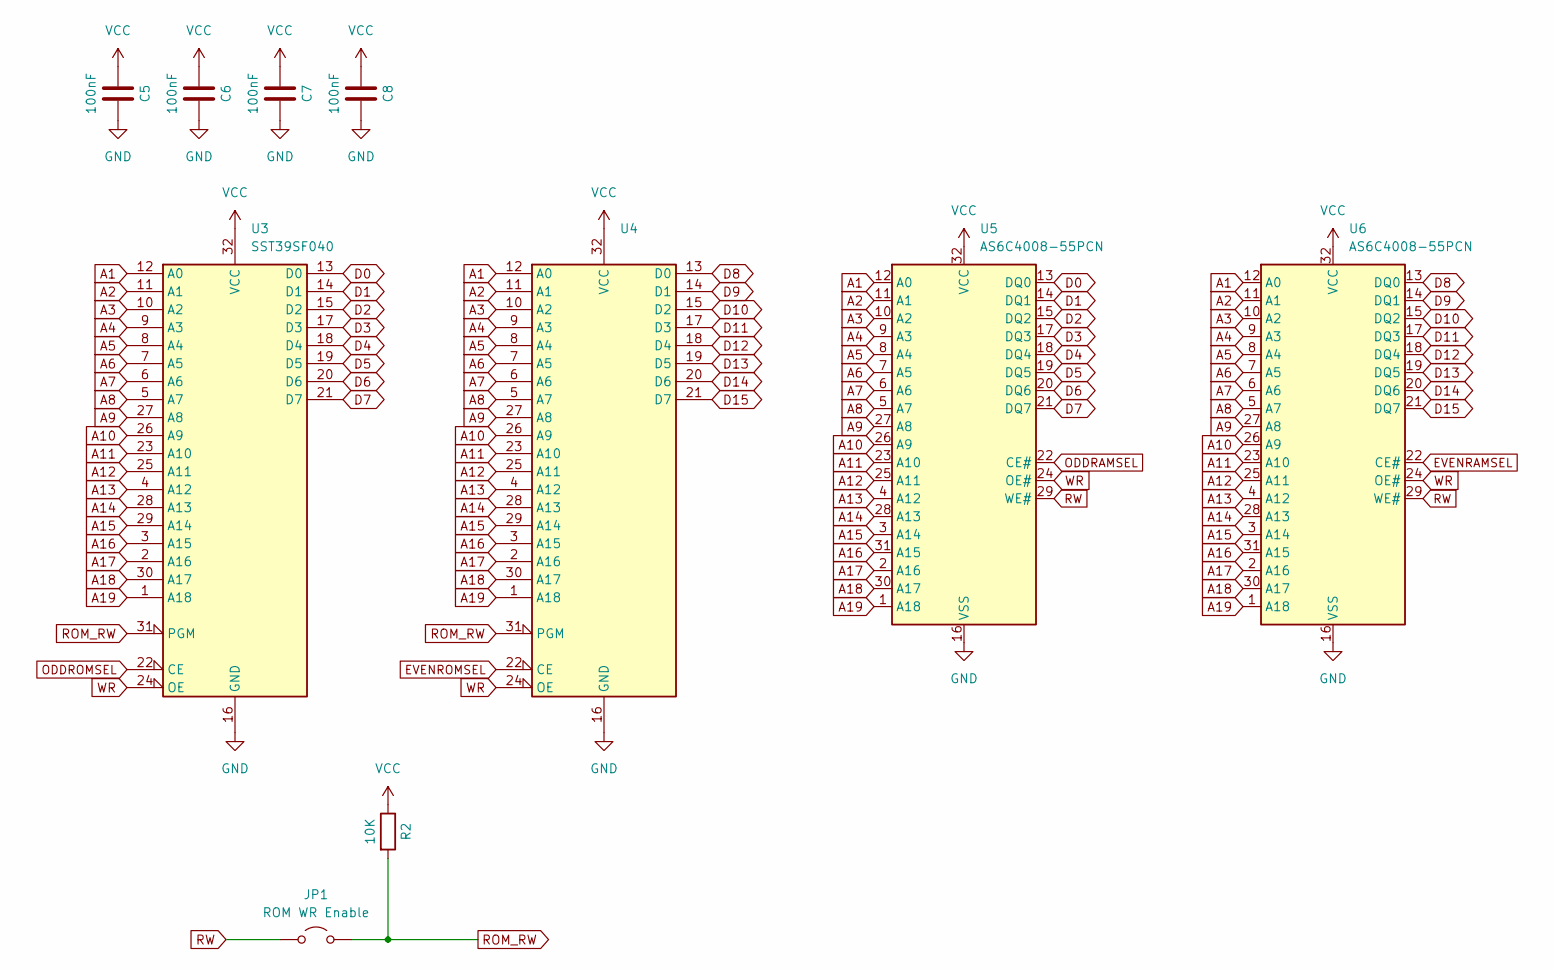
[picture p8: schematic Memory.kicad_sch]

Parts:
C5, C6, C7, C8: 100nF; C_0805_2012Metric_Pad1.18x1.45mm_HandSolder; LCSC C49678
JP1: ROM WR Enable; PinHeader_1x02_P2.54mm_Vertical
R2: 10K; R_0805_2012Metric_Pad1.20x1.40mm_HandSolder; Mouser 0805W8F1002T5E
U3, U4: SST39SF040; PLCC-32_THT-Socket; Mouser SST39SF040-70-4I-NHE
U5, U6: AS6C4008-55PCN; DIP-32_W15.24mm_LongPads; Mouser 913-AS6C4008-55PCN

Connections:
A1: U3.12 (A0), U4.12 (A0), U5.12 (A0), U6.12 (A0); also elsewhere on the board
A2: U3.11 (A1), U4.11 (A1), U5.11 (A1), U6.11 (A1); also elsewhere on the board
A3: U3.10 (A2), U4.10 (A2), U5.10 (A2), U6.10 (A2); also elsewhere on the board
A4: U3.9 (A3), U4.9 (A3), U5.9 (A3), U6.9 (A3); also elsewhere on the board
A5: U3.8 (A4), U4.8 (A4), U5.8 (A4), U6.8 (A4); also elsewhere on the board
A6: U3.7 (A5), U4.7 (A5), U5.7 (A5), U6.7 (A5); also elsewhere on the board
A7: U3.6 (A6), U4.6 (A6), U5.6 (A6), U6.6 (A6); also elsewhere on the board
A8: U3.5 (A7), U4.5 (A7), U5.5 (A7), U6.5 (A7); also elsewhere on the board
A9: U3.27 (A8), U4.27 (A8), U5.27 (A8), U6.27 (A8); also elsewhere on the board
A10: U3.26 (A9), U4.26 (A9), U5.26 (A9), U6.26 (A9); also elsewhere on the board
A11: U3.23 (A10), U4.23 (A10), U5.23 (A10), U6.23 (A10); also elsewhere on the board
A12: U3.25 (A11), U4.25 (A11), U5.25 (A11), U6.25 (A11); also elsewhere on the board
A13: U3.4 (A12), U4.4 (A12), U5.4 (A12), U6.4 (A12); also elsewhere on the board
A14: U3.28 (A13), U4.28 (A13), U5.28 (A13), U6.28 (A13); also elsewhere on the board
A15: U3.29 (A14), U4.29 (A14), U5.3 (A14), U6.3 (A14); also elsewhere on the board
A16: U3.3 (A15), U4.3 (A15), U5.31 (A15), U6.31 (A15); also elsewhere on the board
A17: U3.2 (A16), U4.2 (A16), U5.2 (A16), U6.2 (A16); also elsewhere on the board
A18: U3.30 (A17), U4.30 (A17), U5.30 (A17), U6.30 (A17); also elsewhere on the board
A19: U3.1 (A18), U4.1 (A18), U5.1 (A18), U6.1 (A18); also elsewhere on the board
D0: U3.13 (D0), U5.13 (DQ0); also elsewhere on the board
D1: U3.14 (D1), U5.14 (DQ1); also elsewhere on the board
D2: U3.15 (D2), U5.15 (DQ2); also elsewhere on the board
D3: U3.17 (D3), U5.17 (DQ3); also elsewhere on the board
D4: U3.18 (D4), U5.18 (DQ4); also elsewhere on the board
D5: U3.19 (D5), U5.19 (DQ5); also elsewhere on the board
D6: U3.20 (D6), U5.20 (DQ6); also elsewhere on the board
D7: U3.21 (D7), U5.21 (DQ7); also elsewhere on the board
D8: U4.13 (D0), U6.13 (DQ0); also elsewhere on the board
D9: U4.14 (D1), U6.14 (DQ1); also elsewhere on the board
D10: U4.15 (D2), U6.15 (DQ2); also elsewhere on the board
D11: U4.17 (D3), U6.17 (DQ3); also elsewhere on the board
D12: U4.18 (D4), U6.18 (DQ4); also elsewhere on the board
D13: U4.19 (D5), U6.19 (DQ5); also elsewhere on the board
D14: U4.20 (D6), U6.20 (DQ6); also elsewhere on the board
D15: U4.21 (D7), U6.21 (DQ7); also elsewhere on the board
EVENRAMSEL: U6.22 (CE#); also elsewhere on the board
EVENROMSEL: U4.22 (CE); also elsewhere on the board
GND: C5.2, C6.2, C7.2, C8.2, U3.16 (GND), U4.16 (GND), U5.16 (VSS), U6.16 (VSS); also elsewhere on the board
ODDRAMSEL: U5.22 (CE#); also elsewhere on the board
ODDROMSEL: U3.22 (CE); also elsewhere on the board
ROM_RW: JP1.2 (B), R2.2, U3.31 (PGM), U4.31 (PGM)
RW: JP1.1 (A), U5.29 (WE#), U6.29 (WE#); also elsewhere on the board
VCC: C5.1, C6.1, C7.1, C8.1, R2.1, U3.32 (VCC), U4.32 (VCC), U5.32 (VCC), U6.32 (VCC); also elsewhere on the board
WR: U3.24 (OE), U4.24 (OE), U5.24 (OE#), U6.24 (OE#); also elsewhere on the board

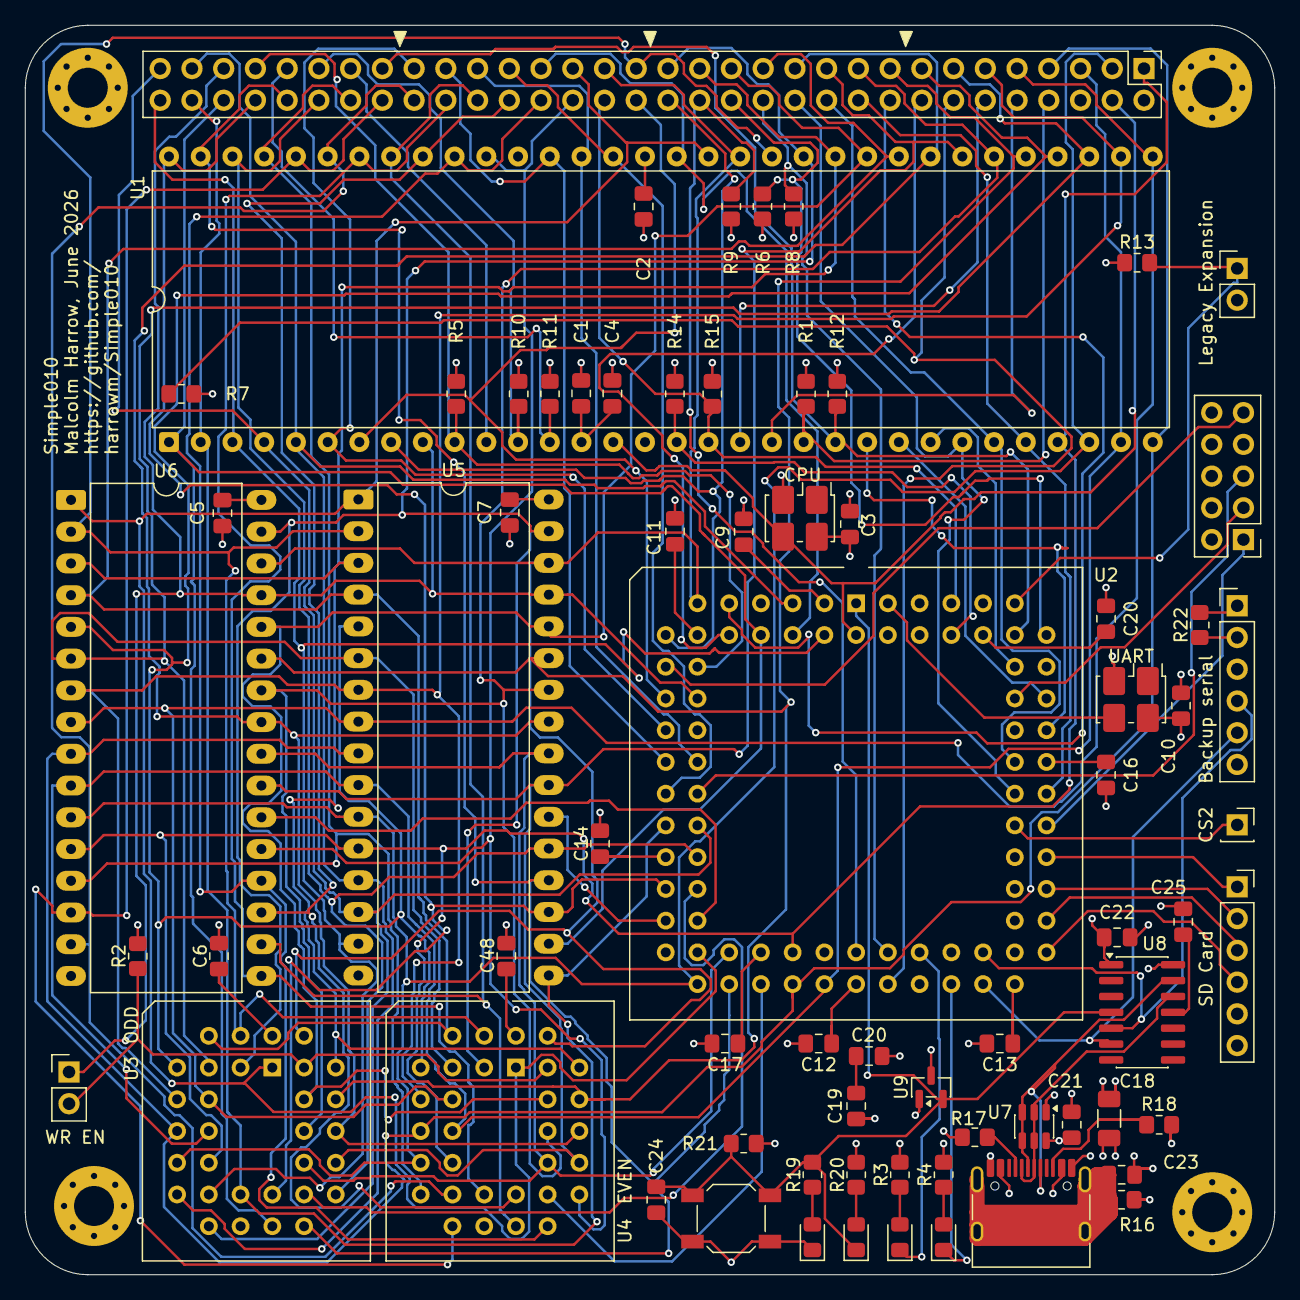
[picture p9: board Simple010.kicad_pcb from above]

Board: 4 copper layers, 100.0 x 100.0 mm, 75 parts (0 on the bottom side), 102 nets.

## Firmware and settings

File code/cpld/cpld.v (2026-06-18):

// rosco_m68k r2 CPLD replacement — ATF1508AS PLCC84
//
// Replaces: IC2 ADDRESS_DECODER, IC3 DUART_SEL, IC5 GLUE_LOGIC,
//           IC6 WATCHDOG, IC4 XR68C681 DUART (UART A only, fixed 115200 8N1),
//           IC7 74LS148 interrupt priority encoder
//
// Clocks:
//   SYS_CLK  (pin 83) 68010 system clock  — watchdog, boot flag, HALT/RESET regs
//   UART_CLK (pin 81) 3.6864 MHz osc      — UART baud (3686400/32 = 115200)
//
// Memory map (identical to r2):
//   $000000-$0FFFFF  1MB  RAM (even/odd)
//   $100000-$DFFFFF  13MB Expansion
//   $E00000-$EFFFFF  1MB  ROM (even/odd)
//   $F00000-$FFFFFF  IO   → UART at $F00000, A1-A4 select register
//
// UART register map (compatible with XR68C681 addresses):
//   A4:A3:A2:A1 = 0001  (offset $02)  SRA   read  — status A
//   A4:A3:A2:A1 = 0011  (offset $06)  RBA   read  — rx buffer A
//   A4:A3:A2:A1 = 0011  (offset $06)  TBA   write — tx buffer A
//   A4:A3:A2:A1 = 1100  (offset $18)  IVR   r/w   — interrupt vector (0x0F at reset for fw detection)
//   A4:A3:A2:A1 = 1101  (offset $1A)  IP    read  — input port (MISO on bit 2)
//   A4:A3:A2:A1 = 1110  (offset $1C)  SETCMD  write — assert output bits (pin low)
//   A4:A3:A2:A1 = 1111  (offset $1E)  RESETCMD write — deassert output bits (pin high)
//   A4:A3:A2:A1 = 0010  (offset $04)  CPLDID  read  — capability byte (see below); write ignored
//   A4:A3:A2:A1 = 0100  (offset $08)  SPIRX   write — trigger one hardware SPI byte receive
//   A4:A3:A2:A1 = 0100  (offset $08)  SPIRX   read  — received byte (valid when SRA bit 2 = 0)
//   SRA (offset $02) bit 2 = spi_busy — 1 while hardware SPI in progress (was 0 on XR68C681)
//   all other addresses: silently ACK'd, no BERR
//
// CPLD detection / capability register (CPLDID, offset $04):
//   The real XR68C681 maps $04 to CRA (Command Register A), which is WRITE-ONLY.
//   Reads of a write-only register return 0xFF or 0x00 (bus float / undefined).
//   The CPLD returns a fixed capability byte here instead, allowing firmware to
//   detect the CPLD and its features with a single read — no write required.
//
//   Bit 7 (0x80): CPLD present                (always 1 in this bitstream)
//   Bit 6 (0x40): HW SPI RX accelerator        (1 = SPIRX register at $08 is available)
//   Bit 5-2     : reserved, read as 0
//   Bit 1-0     : bitstream version             (01 = initial release)
//
//   Value = 0xC1  (CPLD + SPI accel + version 1)
//
//   Firmware usage (note: access the ODD byte address 0xF00005, not 0xF00004):
//     uint8_t cap = *(volatile uint8_t*)0xF00005;  // LDS cycle; uart_sel requires LDS
//     if (cap & 0x80) { /* CPLD present */
//       if (cap & 0x40) { /* HW SPI accelerator available */ }
//     } else           { /* original XR68C681 */ }

`default_nettype none

module cpld (
    // — Clocks —
    input         SYS_CLK,

    // — 68010 address bus —
    // Note: A6-A17 not connected on revised board (simplified uart_sel no
    // longer needs them; freed those CPLD pins for IRQ/IPL signals below).
    input         A1, A2, A3, A4,
    input         A18, A19, A20, A21, A22, A23,

    // — 68010 bus control —
    input         AS, RW, UDS, LDS,
    input         FC0, FC1, FC2,

    // — Hardware reset (active low pushbutton) —
    input         HWRST,

    // — Open-drain bus signals —
    output        HALT,
    output        RESET,
    inout         DTACK,
    inout         BERR,

    // — Memory chip selects (active low) —
    output        nEVENRAMSEL,
    output        nODDRAMSEL,
    output        nEVENROMSEL,
    output        nODDROMSEL,
    output        nEXPSEL,

    // — External DTACK from expansion bus —
    input         LGEXP,

    // — Misc —
    output        WR,
    output        nIOSEL,   // I/O range select ($F00000-$FFFFFF) — for expansion cards

    // — CPU data bus (bidirectional, for UART register access) —
    inout  [7:0]  D,

    // — UART A —
    input         UART_CLK,    // 3.6864 MHz crystal oscillator
    output        TXA,
    input         RXA,

    // — SPI / GPIO output port (XR68C681 OP bit mapping) —
    output        SPI_MOSI,    // OP6
    input         SPI_MISO,    // IP2
    output        SPI_SCK,     // OP4
    output        SPI_nCS,     // OP2
    output        SPI_nCS1,    // OP7
    output        LED_RED,     // OP3
    output        LED_GREEN,   // OP5

    // — Interrupt priority encoder (replaces IC7 74LS148) —
    // Expansion bus IRQ lines, active low, open-collector from expansion cards.
    // Pull-up resistors to +5V are REQUIRED on the board — the ATF1508AS has
    // no internal pull-ups.  These correspond to the r2 pull-up network:
    //   nIRQ2 — R15 (4.7kΩ to VCC)
    //   nIRQ3 — R16 (4.7kΩ to VCC)
    //   nIRQ5 — R18 (4.7kΩ to VCC)
    //   nIRQ6 — R17 (4.7kΩ to VCC)
    // The UART interrupt (formerly DUAIRQ / R12) is sourced internally from
    // rx_ready and does not require an external pin or pull-up resistor.
    input         nIRQ2,
    input         nIRQ3,
    input         nIRQ5,
    input         nIRQ6,

    // 68010 interrupt priority lines, active low (connect directly to CPU IPL2-0)
    output        IPL2,
    output        IPL1,
    output        IPL0
);

// ============================================================
// GLUE LOGIC (IC5)
// ============================================================

// CPU space: FC = 111
wire cpu_space = FC2 & FC1 & FC0;

// HALT and RESET: driven low (open-drain) during reset pulse.
// halt_rel/reset_rel reset to 0 (uses global GCLRn — free fanin).
// Released (set to 1) on first SYS_CLK after HWRST goes high.
// (* keep *) prevents Yosys 0.66 from merging halt_rel/reset_rel into a single FF.
// When merged, dfflibmap creates a floating ENA net (no driver) that crashes the fitter.
(* keep *) reg halt_rel, reset_rel;
always @(posedge SYS_CLK or negedge HWRST) begin
    if (!HWRST) begin
        halt_rel  <= 1'b0;
        reset_rel <= 1'b0;
    end else begin
        halt_rel  <= 1'b1;
        reset_rel <= 1'b1;
    end
end
assign HALT  = halt_rel  ? 1'bz : 1'b0;
assign RESET = reset_rel ? 1'bz : 1'b0;

// CPUSP: HIGH for all normal supervisor/user accesses (FC != 111).
// Matches IC5 GAL output: /CPUSP = /HWRST * FC2 * FC1 * FC0 drives pin HIGH when
// FC != 111, LOW during CPU-space (interrupt-ack) cycles. IC2 uses CPUSP active-high
// to gate RAM/ROM/EXP/IO — so those are accessible for normal accesses, blocked during IACK.
wire cpusp = ~cpu_space;
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

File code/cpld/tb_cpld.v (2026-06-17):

// Testbench for cpld.v — address decoder and interrupt encoder
//
// Run with:
//   iverilog -DSIMULATION -o tb_cpld tb_cpld.v cpld.v && vvp tb_cpld
//
// 68010 FC encoding:
//   FC=3'b101 — supervisor data   (normal data R/W)
//   FC=3'b110 — supervisor program (instruction fetch)
//   FC=3'b111 — CPU space         (interrupt acknowledge — blocks memory)
//
// 68010 active-low IPL encoding (IPL2:IPL1:IPL0):
//   3'b111 = no interrupt (level 0)
//   3'b101 = level 2  (~2 = ~3'b010)
//   3'b100 = level 3  (~3 = ~3'b011)
//   3'b011 = level 4  (~4 = ~3'b100)
//   3'b010 = level 5  (~5 = ~3'b101)
//   3'b001 = level 6  (~6 = ~3'b110)

`timescale 1ns/1ps
`default_nettype none

module tb_cpld;

// ----------------------------------------------------------------
// Clocks
// ----------------------------------------------------------------
reg SYS_CLK  = 0;
reg UART_CLK = 0;
always #62  SYS_CLK  = ~SYS_CLK;   // ~8 MHz
always #135 UART_CLK = ~UART_CLK;  // ~3.7 MHz

// ----------------------------------------------------------------
// DUT inputs
// ----------------------------------------------------------------
reg        HWRST;
reg [23:0] ADDR;
reg        AS, RW, UDS, LDS;
reg [2:0]  FC;
reg        LGEXP;
reg        nIRQ2_drv, nIRQ3_drv, nIRQ5_drv, nIRQ6_drv;
reg        RXA;
reg        SPI_MISO;
reg  [7:0] D_drv;
reg        D_oe;

// ----------------------------------------------------------------
// DUT outputs / inout wires
// ----------------------------------------------------------------
wire HALT, RESET;
wire DTACK, BERR;
wire nEVENRAMSEL, nODDRAMSEL, nEVENROMSEL, nODDROMSEL, nEXPSEL;
wire WR, nIOSEL;
wire [7:0] D;
wire TXA;
wire SPI_MOSI, SPI_SCK, SPI_nCS, SPI_nCS1, LED_RED, LED_GREEN;
wire IPL0, IPL1, IPL2;

// Pull-ups on open-drain/tristate signals
tri1 DTACK_pu;
tri1 BERR_pu;
assign DTACK_pu = DTACK;
assign BERR_pu  = BERR;

// Open-collector IRQ lines (1 = deasserted via pull-up, 0 = asserted)
wire nIRQ2 = nIRQ2_drv;
wire nIRQ3 = nIRQ3_drv;
wire nIRQ5 = nIRQ5_drv;
wire nIRQ6 = nIRQ6_drv;

assign D = D_oe ? D_drv : 8'hzz;

// ----------------------------------------------------------------
// DUT instantiation
// ----------------------------------------------------------------
cpld dut (
    .SYS_CLK  (SYS_CLK),
    .UART_CLK (UART_CLK),
    .A1  (ADDR[1]),  .A2  (ADDR[2]),  .A3  (ADDR[3]),  .A4  (ADDR[4]),
    .A18 (ADDR[18]), .A19 (ADDR[19]), .A20 (ADDR[20]),
    .A21 (ADDR[21]), .A22 (ADDR[22]), .A23 (ADDR[23]),
    .AS(AS), .RW(RW), .UDS(UDS), .LDS(LDS),
    .FC0(FC[0]), .FC1(FC[1]), .FC2(FC[2]),
    .HWRST(HWRST),
    .HALT(HALT), .RESET(RESET), .DTACK(DTACK), .BERR(BERR),
    .nEVENRAMSEL(nEVENRAMSEL), .nODDRAMSEL(nODDRAMSEL),
    .nEVENROMSEL(nEVENROMSEL), .nODDROMSEL(nODDROMSEL),
    .nEXPSEL(nEXPSEL),
    .LGEXP(LGEXP),
    .WR(WR), .nIOSEL(nIOSEL),
    .D(D),
    .TXA(TXA), .RXA(RXA),
    .SPI_MOSI(SPI_MOSI), .SPI_MISO(SPI_MISO), .SPI_SCK(SPI_SCK),
    .SPI_nCS(SPI_nCS), .SPI_nCS1(SPI_nCS1),
    .LED_RED(LED_RED), .LED_GREEN(LED_GREEN),
    .nIRQ2(nIRQ2), .nIRQ3(nIRQ3), .nIRQ5(nIRQ5), .nIRQ6(nIRQ6),
    .IPL0(IPL0), .IPL1(IPL1), .IPL2(IPL2)
);

// ----------------------------------------------------------------
// Helpers
// ----------------------------------------------------------------
integer pass_count = 0;
integer fail_count = 0;

task check_sig;
    input [256:0] msg;
    input         got;
    input         expected;
    begin
        if (got === expected) begin
            pass_count = pass_count + 1;
        end else begin
            $display("FAIL  %s: got %b expected %b", msg, got, expected);
            fail_count = fail_count + 1;
        end
    end
endtask

task check_asserted;   // active-low signal is low
    input [256:0] msg;
    input         sig;
    begin check_sig(msg, sig, 1'b0); end
endtask

task check_deasserted; // active-low signal is high (or Z with pull-up)
    input [256:0] msg;
    input         sig;
    begin
        if (sig === 1'b1 || sig === 1'bz) pass_count = pass_count + 1;
        else begin
            $display("FAIL  %s: expected deasserted (1/z), got %b", msg, sig);
            fail_count = fail_count + 1;
        end
    end
endtask

task bus_read;
    input [23:0] addr;
    input [2:0]  fc;
    begin
        ADDR = addr; FC = fc; RW = 1; UDS = 0; LDS = 0; AS = 0;
        #10;
    end
endtask

task bus_idle;
    begin
        AS = 1; UDS = 1; LDS = 1; RW = 1; LGEXP = 0;
        #10;
    end
endtask

task do_reset;
    begin
        HWRST = 0;
        @(posedge SYS_CLK); @(posedge SYS_CLK);
        HWRST = 1;
        @(posedge SYS_CLK); @(posedge SYS_CLK);
    end
endtask

// ----------------------------------------------------------------
// Initial state
// ----------------------------------------------------------------
initial begin
    AS = 1; RW = 1; UDS = 1; LDS = 1; FC = 3'b101;
    ADDR = 24'h0; LGEXP = 0;
    nIRQ2_drv = 1; nIRQ3_drv = 1; nIRQ5_drv = 1; nIRQ6_drv = 1;
    RXA = 1; SPI_MISO = 1; D_drv = 8'h0; D_oe = 0; HWRST = 1;
end
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

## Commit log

2026-06-02 Sort out R and C types
    [CPU.kicad_sch, Memory.kicad_sch, USB.kicad_sch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]
2026-06-03 Clean ERCC on schmatic
    [USB.kicad_sch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]
2026-06-17 Further improvements on CPLD pin placement to improve routing
    [CPU.kicad_sch, Memory.kicad_sch, Simple010.kicad_pcb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]
2026-06-17 Add fetch-datasheet skill and datasheets for all board components
    Adds:
    - .claude/commands/fetch-datasheet.md — reusable skill for finding and
    downloading component datasheets with LCSC and Mouser numbers
    - design/datasheets/ — PDFs for all 11 unique active components:
    MC68010, ATF1508AS, SST39SF040, AS6C4008, MCP2221A, USBLC6-2SC6,
    UM809SS, ECS-3961/SG-5032CAN (both frequencies), LTST-C170KGKT/KRKT
    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
2026-06-17 Fix USB-C connector: update to Korean Hroparts TYPE-C-31-M-12 (C165948)
    Corrects J3 from the erroneous C230736 (Jing Extension) to C165948
    (Korean Hroparts TYPE-C-31-M-12). Updates schematic, adds datasheet,
    and removes the now-resolved note from the INDEX.
    [USB.kicad_sch]
2026-06-18 Fix all R/C part numbers: switch to JLCPCB basic parts, correct footprints
    - Replace all non-basic LCSC numbers with JLCPCB basic equivalents (no
    extended part setup fees): Samsung MLCCs for caps, UNI-ROYAL 0805W8F
    series for resistors
    - Fix C49 footprint: 1210 → 1206 to match Samsung CL31A476MPHNNNE
    - Correct previously wrong LCSC numbers (C17512→C17513, C17515→C17673,
    C135808→C96123) and missing R17 part numbers
    - Update all Mouser numbers to match the LCSC manufacturer throughout
    - Standardise all resistor footprints to HandSolder pad variant
    - Update datasheets/INDEX.md with verified basic part table
    [CPU.kicad_sch, Memory.kicad_sch, Simple010.kicad_pcb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]
2026-06-18 Change U11 reset supervisor from UM809SS (2.93V) to LM809M3-4.63/NOPB (4.63V)
    4.63V threshold gives proper brownout protection on a 5V supply — the 2.93V
    part would not trigger until VCC had fallen well below all IC minimum specs.
    LM809M3-4.63/NOPB is pin-compatible (same SOT-23-3 footprint), push-pull
    active-low, and a JLCPCB Basic part (C2066444). R17 pull-up unchanged.
    [USB.kicad_sch]
2026-06-18 Update IC part numbers: SST39SF040, AS6C4008, LM809M3-4.63/NOPB
    - SST39SF040 (U14/U15): Mouser 579-SST39SF040-70-4I-NHE (PLCC-32,
    industrial grade); LCSC has no PLCC-32 variant in stock
    - AS6C4008-55PCN (U16/U17): fix LCSC C62646→C1350141 (was invalid/404);
    Mouser 913-AS6C4008-55PCN has stock, LCSC currently OOS
    - LM809M3-4.63/NOPB (U11): add LCSC C2066444 and Mouser part number
    properties to schematic
    [Memory.kicad_sch, USB.kicad_sch]
2026-06-18 Fix even/odd memory bus wiring and route PCB
    - Connect U15 (even ROM) and U17 (even RAM) data pins to D8-D15 instead
    of D0-D7: upper byte was completely unconnected, causing half-garbage
    reads and lost writes on all 16-bit accesses
    - Reduce R32/R33 LED resistors from 4.7k to 1k (MCP2221A GPIO is 3.3V,
    4.7k gave only 0.26mA — too dim)
    - Initial PCB layout and routing
    [CPU.kicad_sch, Memory.kicad_sch, Simple010.kicad_pcb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]
2026-06-18 Update INDEX.md reference numbers to match renumbered schematic
    U10→U1 (CPU), U14/U15→U3/U4 (ROM), U16/U17→U5/U6 (RAM),
    U1→U8 (MCP2221A), U9→U7 (USBLC6), U11→U9 (LM809),
    Y4/Y3→Y1/Y2 (oscillators)
2026-06-18 Update INDEX.md passive and LED reference numbers
    Reflects renumbered C, R, and LED designators after schematic cleanup.
2026-06-18 Fix CPLD detection register address in docs: 0xF00004 → 0xF00005
    uart_sel is gated on ~LDS (lower data strobe), so the CPLD only responds
    to odd-byte (LDS) accesses. C firmware must read 0xF00005, not 0xF00004.
    Update cpld.v firmware-usage comment and CLAUDE.md accordingly.
    [cpld.v]
2026-06-18 Add README.md with hardware overview, build instructions, and firmware section
    Covers memory map, CPLD blocks, repo layout, build commands, firmware
    compatibility and Simple010-specific CPLD/SPI detection changes.
2026-06-18 Update README.md with SPI accelerator firmware change
    Document bbspi.c changes: BBSPI_initialize() detection, accelerated
    recv sequence table, and fallback behaviour on original rosco hardware.
2026-06-18 Fix MCP2221A description: serial only, SPI pins unconnected
    Netlist confirms MCP2221A GP0-GP3/SCL/SDA are all unconnected.
    SD card SPI (SPICLK/SPICS/SPIMOSI/SPIMISO) runs directly between
    J8 and the CPLD (U2), not via MCP2221A. Update README and CLAUDE.md.
2026-06-18 Update KiCad design files and add fabrication outputs
    Schematic and PCB updates including component renumbering (ICs, passives,
    LEDs, oscillators). Add JLCPCB fabrication toolkit settings and v1
    production outputs (gerbers zip, IPC netlist).
    [CPU.kicad_sch, Memory.kicad_sch, Simple010.kicad_pcb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]
2026-06-19 Add board render image and 3D models for PLCC84, PLCC32, oscillators, USB-C
    [8432-11b1-01.stp, PLCC32_NH_SST_MCH.step, PLCC84_MCH.step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]
2026-06-21 Add Simple010-16 design directory (16 MB SRAM variant)
    Copied from design/ as starting point for 16 MB SRAM board variant.
    [8432-11b1-01.stp, CPU.kicad_sch, Memory.kicad_sch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]
2026-06-21 Reorganise design/ — move Simple010 files into design/Simple010/
    Prepares for multi-board repo layout alongside Simple010-16.
    datasheets/ remains shared at the design/ level.
    [8432-11b1-01.stp, CPU.kicad_sch, Memory.kicad_sch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]
